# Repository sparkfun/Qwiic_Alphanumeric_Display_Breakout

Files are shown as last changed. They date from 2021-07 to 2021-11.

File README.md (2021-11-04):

SparkFun Qwiic Alphanumeric Display
========================================

Qwiic Alphanumeric Display - Pink (https://cdn.sparkfun.com/assets/parts/1/5/8/5/5/16919-SparkFun_Qwiic_Alphanumeric_Display_-_Pink-Demo.jpg)

[*Qwiic Alphanumeric Display - Pink (COM-16919)*](https://www.sparkfun.com/products/16919)

Qwiic Alphanumeric Display - Green (https://cdn.sparkfun.com/assets/parts/1/8/0/2/2/18566-SparkFun_Qwiic_Alphanumeric_Display_-_Green-Demo.jpg)

[*Qwiic Alphanumeric Display - Green (COM-18566)*](https://www.sparkfun.com/products/18566)

Qwiic Alphanumeric Display - Red (https://cdn.sparkfun.com/assets/parts/1/5/8/5/2/16916-SparkFun_Qwiic_Alphanumeric_Display_-_Red-Demo.jpg)

[*Qwiic Alphanumeric Display - Red (COM-16916)*](https://www.sparkfun.com/products/16916)

Qwiic Alphanumeric Display - Blue (https://cdn.sparkfun.com/assets/parts/1/5/8/5/3/16917-SparkFun_Qwiic_Alphanumeric_Display_-_Blue-Demo.jpg)

[*Qwiic Alphanumeric Display - Blue (COM-16917)*](https://www.sparkfun.com/products/16917)

Qwiic Alphanumeric Display - Purple (https://cdn.sparkfun.com/assets/parts/1/5/8/5/4/16918-SparkFun_Qwiic_Alphanumeric_Display_-_Purple-Demo.jpg)

[*Qwiic Alphanumeric Display - Purple (COM-16918)*](https://www.sparkfun.com/products/16918)

Qwiic Alphanumeric Display - White (https://cdn.sparkfun.com/assets/parts/1/8/0/2/0/18565-SparkFun_Qwiic_Alphanumeric_Display_-_White-Demo.jpg)

[*Qwiic Alphanumeric Display - White (COM-18565)*](https://www.sparkfun.com/products/18565)

We are quite familiar with seven-segment displays. We see them on our alarm clocks, ovens, and microwaves. By adding more segments to each digit you can display more than just numbers! Introducing the brand new SparkFun Qwiic Alphanumeric Display. These fourteen-segment digits allow you to display all sorts of numbers, characters, and symbols. With [Qwiic](https://www.sparkfun.com/qwiic), simply plug it in and go. No soldering, no figuring out which is SDA or SCL, and no voltage regulation or translation required! 

The [SparkFun Alphanumeric Display Arduino library](https://github.com/sparkfun/SparkFun_Alphanumeric_Display_Arduino_Library) makes printing strings to the display as easy as calling the print() function. With this library, you'll be able to send I<sup>2</sup>C commands to the VK16K33 LED driver chip to light up segments (including the decimal point or colon) and even scroll your string across the display. You can download the library through the Arduino library manager by searching 'SparkFun Alphanumeric Display' or you can get the GitHub repo as a .zip file and install the library from there.

The VK16K33 also supports I<sup>2</sup>C address configuration. Simply close a combination of the address jumpers on the back and you can communicate with up to four displays on the same bus. Our slim board design also features detachable standoff holes, vertical Qwiic connectors, and internal mounting holes.

SparkFun labored with love to design this board. Feel like supporting open source hardware? 
Buy a [board]() from SparkFun!

Repository Contents
-------------------

* **/Documents** - Data sheet for the LED Driver and Alphanumeric Displays (Blue and Red)
* **/Hardware** - Eagle design files (.brd, .sch)
* **/Production** - Production panel files (.brd) within the Production folder

Documentation
--------------
* **[Library](https://github.com/sparkfun/SparkFun_Alphanumeric_Display_Arduino_Library)** - <LANGUAGE> library for the Qwiic Alphanumeric Display Breakout.
* **[Hookup Guide](https://learn.sparkfun.com/tutorials/sparkfun-qwiic-alphanumeric-display-hookup-guide)** - Basic hookup guide for the Qwiic Alphanumeric Display Breakout.

License Information
-------------------

This product is _**open source**_! 

Please review the LICENSE.md file for license information. 

If you have any questions or concerns on licensing, please contact technical support on our [SparkFun forums](https://forum.sparkfun.com/viewforum.php?f=152).

Distributed as-is; no warranty is given.

- Your friends at SparkFun.

_<COLLABORATION CREDIT>_

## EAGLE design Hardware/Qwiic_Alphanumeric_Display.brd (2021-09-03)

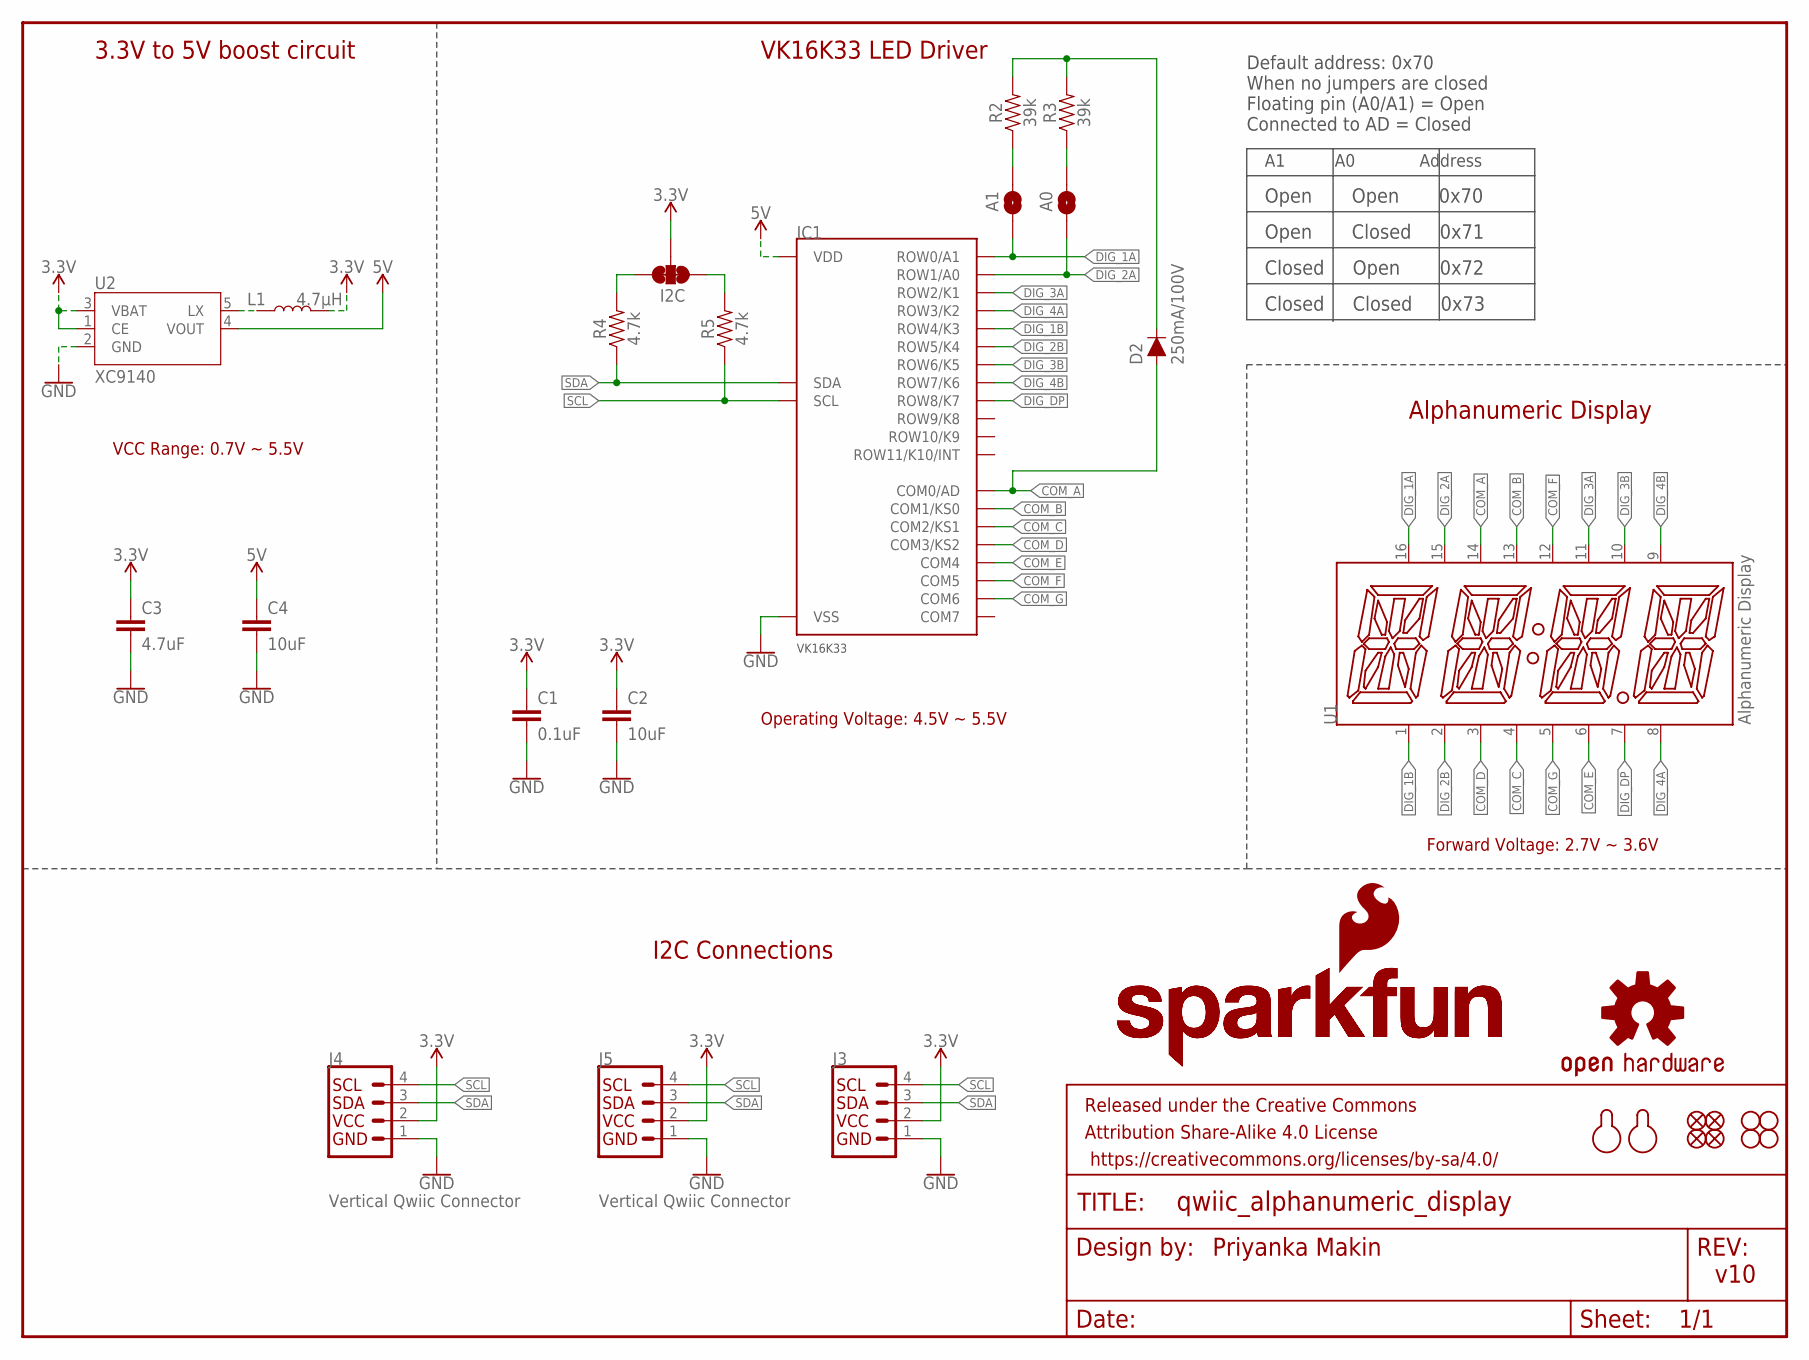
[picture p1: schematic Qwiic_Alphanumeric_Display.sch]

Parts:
A0, A1: JUMPER-SMT_2_NO_SILK; SMT-JUMPER_2_NO_SILK
C1: 0.1uF; 0603
C2, C4: 10uF; 0603
C3: 4.7uF; 0603
D2: 250mA/100V; SOD-323
FD1, FD2, FD3, FD4: FIDUCIAL1X2; FIDUCIAL-1X2
FRAME1: FRAME-LETTER; CREATIVE_COMMONS
H1, H2, H3, H4: STAND-OFF
I2C: JUMPER-SMT_3_2-NC_TRACE_NO-SILK; SMT-JUMPER_3_2-NC_TRACE_NO-SILK
IC1: VK16K33VK16K33; VK16K33
J3: I2C_STANDARD_NO_SILK; 1X04_NO_SILK
J4, J5: Vertical Qwiic Connector; JST04_1MM_VERT
L1: 4.7µH; INDUCTOR_4.7UH
LOGO1: OSHW-LOGOMINI; OSHW-LOGO-MINI
LOGO2, LOGO3: SFE_LOGO_NAME.1_INCH; SFE_LOGO_NAME_.1
LOGO4: SFE_LOGO_FLAME.1_INCH; SFE_LOGO_FLAME_.1
R2, R3: 39k; 0603
R4, R5: 4.7k; 0402-TIGHT
U1: Alphanumeric Display; SILSMART_DISPLAY
U2: XC9140; SOT23-5
U$3, U$7: MOUNTING_HOLE_M2-0.4X6

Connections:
3.3V: C1.1, C2.1, C3.1, I2C.2, J3.2, J4.2, J5.2, L1.P$2 (2), U2.1 (CE), U2.3 (VBAT)
5V: C4.1, IC1.24 (VDD), U2.4 (VOUT)
COM_A: D2.A, IC1.2 (COM0/AD), U1.14 (COM_A)
COM_B: IC1.3 (COM1/KS0), U1.13 (COM_B)
COM_C: IC1.4 (COM2/KS1), U1.4 (COM_C)
COM_D: IC1.5 (COM3/KS2), U1.3 (COM_D)
COM_E: IC1.6 (COM4), U1.6 (COM_E)
COM_F: IC1.7 (COM5), U1.12 (COM_F)
COM_G: IC1.8 (COM6), U1.5 (COM_G1)
DIG_1A: A1.1, IC1.21 (ROW0/A1), U1.16 (DIG_1A)
DIG_1B: IC1.17 (ROW4/K3), U1.1 (DIG_1B)
DIG_2A: A0.1, IC1.20 (ROW1/A0), U1.15 (DIG_2A)
DIG_2B: IC1.16 (ROW5/K4), U1.2 (DIG_2B)
DIG_3A: IC1.19 (ROW2/K1), U1.11 (DIG_3A)
DIG_3B: IC1.15 (ROW6/K5), U1.10 (DIG_3B)
DIG_4A: IC1.18 (ROW3/K2), U1.8 (DIG_4A)
DIG_4B: IC1.14 (ROW7/K6), U1.9 (DIG_4B)
DIG_DP: IC1.13 (ROW8/K7), U1.7 (DIG_DP)
GND: C1.2, C2.2, C3.2, C4.2, IC1.1 (VSS), J3.1, J4.1, J5.1, U2.2 (GND)
unnamed: I2C.3, R4.2
unnamed: A1.2, R2.1
unnamed: A0.2, R3.1
unnamed: I2C.1, R5.2
unnamed: D2.C, R2.2, R3.2
unnamed: L1.P$1 (1), U2.5 (LX)
SCL: IC1.22 (SCL), J3.4, J4.4, J5.4, R5.1
SDA: IC1.23 (SDA), J3.3, J4.3, J5.3, R4.1

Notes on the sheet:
Priyanka Makin
I2C Connections
A1 A0 Address
Default address: 0x70 When no jumpers are closed Floating pin (A0/A1) = Open Connected to AD = Closed
v10
Alphanumeric Display
VK16K33 LED Driver
3.3V to 5V boost circuit
VK16K33
VCC Range: 0.7V ~ 5.5V
Operating Voltage: 4.5V ~ 5.5V
Forward Voltage: 2.7V ~ 3.6V
Open Closed 0x71
Open Open 0x70
Closed Open 0x72
Closed Closed 0x73

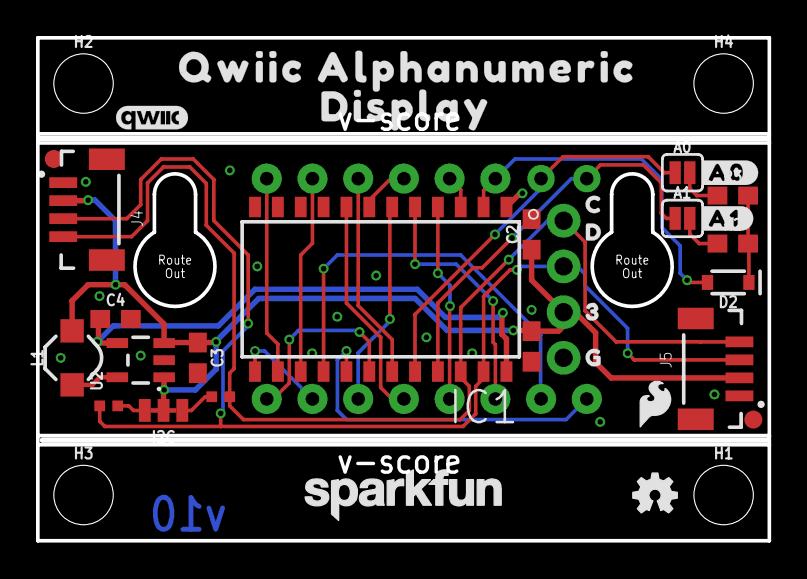
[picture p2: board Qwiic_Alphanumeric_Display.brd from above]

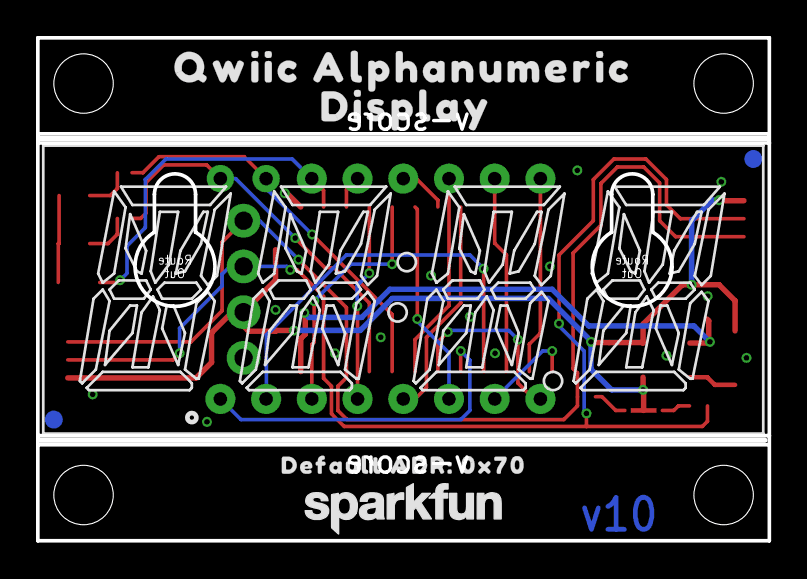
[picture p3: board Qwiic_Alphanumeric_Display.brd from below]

Board: 2 copper layers, 40.6 x 27.9 mm, 46 parts (7 on the bottom side), 27 nets.

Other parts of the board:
U$1: DEFAULT_ADR#_0X700
U$6: QWIIC_4MM
U$8, U$9: QWIIC_ALPHANUMERIC0
U$10, U$11: DISPLAY0
U$12: #A0#0
U$13: #A1#0
U$14: C0
U$15: D0
U$16: 30
U$17: G0

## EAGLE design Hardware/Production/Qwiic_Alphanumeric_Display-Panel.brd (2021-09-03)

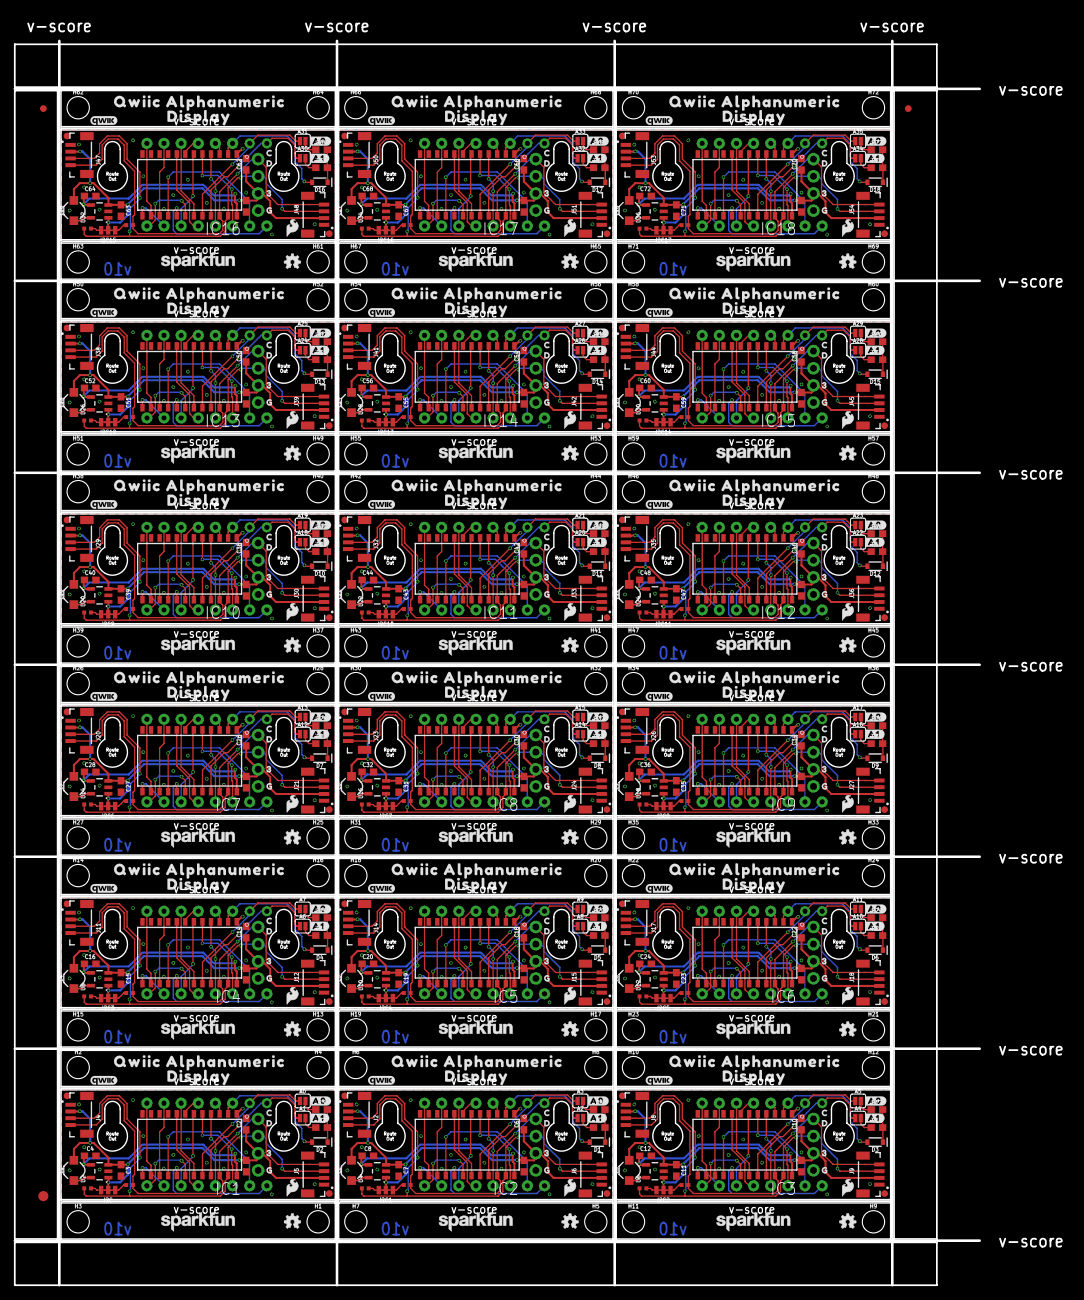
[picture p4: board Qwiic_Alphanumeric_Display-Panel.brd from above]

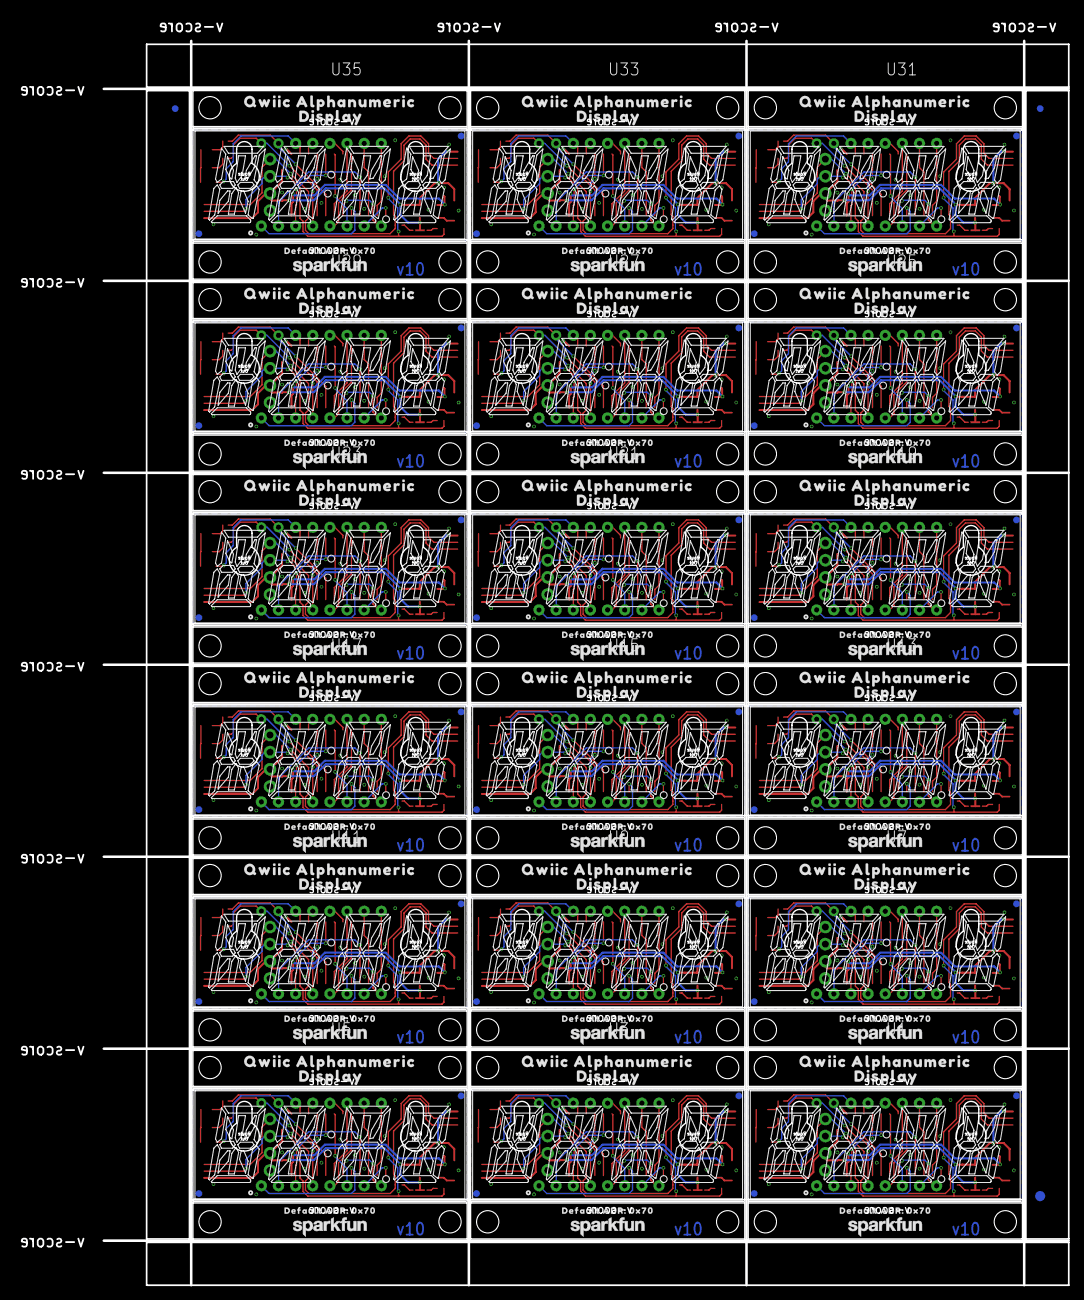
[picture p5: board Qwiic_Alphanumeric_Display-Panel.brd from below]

Board: 2 copper layers, 143.0 x 184.4 mm, 816 parts (129 on the bottom side), 486 nets.

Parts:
A0, A1, A2, A3, A4, A5, A6, A7, A8, A9, A10, A11, A12, A13, A14, A15, A16, A17, A18, A19, A20, A21, A22, A23, A24, A25, A26, A27, A28, A29, A30, A31, A32, A33, A34, A35: JUMPER-SMT_2_NO_SILK; SMT-JUMPER_2_NO_SILK
C1, C5, C9, C13, C17, C21, C25, C29, C33, C37, C41, C45, C49, C53, C57, C61, C65, C69: 0.1uF; 0603
C2, C4, C6, C8, C10, C12, C14, C16, C18, C20, C22, C24, C26, C28, C30, C32, C34, C36, C38, C40, C42, C44, C46, C48, C50, C52, C54, C56, C58, C60, C62, C64, C66, C68, C70, C72: 10uF; 0603
C3, C7, C11, C15, C19, C23, C27, C31, C35, C39, C43, C47, C51, C55, C59, C63, C67, C71: 4.7uF; 0603
D1, D2, D3, D4, D5, D6, D7, D8, D9, D10, D11, D12, D13, D14, D15, D16, D17, D18: 250mA/100V; SOD-323
E$1, E$2, E$3, E$4: FIDUCIAL-1X2
E$5, E$6: FIDUCIAL-1.5X3
FD1, FD2, FD3, FD4, FD5, FD6, FD7, FD8, FD9, FD10, FD11, FD12, FD13, FD14, FD15, FD16, FD17, FD18, FD19, FD20, FD21, FD22, FD23, FD24, FD25, FD26, FD27, FD28, FD29, FD30, FD31, FD32, FD33, FD34, FD35, FD36, FD37, FD38, FD39, FD40, FD41, FD42, FD43, FD44, FD45, FD46, FD47, FD48, FD49, FD50, FD51, FD52, FD53, FD54, FD55, FD56, FD57, FD58, FD59, FD60, FD61, FD62, FD63, FD64, FD65, FD66, FD67, FD68, FD69, FD70, FD71, FD72: FIDUCIAL1X2; FIDUCIAL-1X2
H1, H2, H3, H4, H5, H6, H7, H8, H9, H10, H11, H12, H13, H14, H15, H16, H17, H18, H19, H20, H21, H22, H23, H24, H25, H26, H27, H28, H29, H30, H31, H32, H33, H34, H35, H36, H37, H38, H39, H40, H41, H42, H43, H44, H45, H46, H47, H48, H49, H50, H51, H52, H53, H54, H55, H56, H57, H58, H59, H60, H61, H62, H63, H64, H65, H66, H67, H68, H69, H70, H71, H72: STAND-OFF
I2C, I2C1, I2C2, I2C3, I2C4, I2C5, I2C6, I2C7, I2C8, I2C9, I2C10, I2C11, I2C12, I2C13, I2C14, I2C15, I2C16, I2C17: JUMPER-SMT_3_2-NC_TRACE_NO-SILK; SMT-JUMPER_3_2-NC_TRACE_NO-SILK
IC1, IC2, IC3, IC4, IC5, IC6, IC7, IC8, IC9, IC10, IC11, IC12, IC13, IC14, IC15, IC16, IC17, IC18: VK16K33
J1, J3, J7, J10, J13, J16, J19, J22, J25, J28, J31, J34, J37, J40, J43, J46, J49, J52: 1X04_NO_SILK
J2, J4, J5, J6, J8, J9, J11, J12, J14, J15, J17, J18, J20, J21, J23, J24, J26, J27, J29, J30, J32, J33, J35, J36, J38, J39, J41, J42, J44, J45, J47, J48, J50, J51, J53, J54: Vertical Qwiic Connector; JST04_1MM_VERT
L1, L2, L3, L4, L5, L6, L7, L8, L9, L10, L11, L12, L13, L14, L15, L16, L17, L18: 4.7µH; INDUCTOR_4.7UH
LOGO1, LOGO5, LOGO9, LOGO13, LOGO17, LOGO21, LOGO25, LOGO29, LOGO33, LOGO37, LOGO41, LOGO45, LOGO49, LOGO53, LOGO57, LOGO61, LOGO65, LOGO69: OSHW-LOGOMINI; OSHW-LOGO-MINI
LOGO2, LOGO3, LOGO6, LOGO7, LOGO10, LOGO11, LOGO14, LOGO15, LOGO18, LOGO19, LOGO22, LOGO23, LOGO26, LOGO27, LOGO30, LOGO31, LOGO34, LOGO35, LOGO38, LOGO39, LOGO42, LOGO43, LOGO46, LOGO47, LOGO50, LOGO51, LOGO54, LOGO55, LOGO58, LOGO59, LOGO62, LOGO63, LOGO66, LOGO67, LOGO70, LOGO71: SFE_LOGO_NAME.1_INCH; SFE_LOGO_NAME_.1
LOGO4, LOGO8, LOGO12, LOGO16, LOGO20, LOGO24, LOGO28, LOGO32, LOGO36, LOGO40, LOGO44, LOGO48, LOGO52, LOGO56, LOGO60, LOGO64, LOGO68, LOGO72: SFE_LOGO_FLAME.1_INCH; SFE_LOGO_FLAME_.1
R1, R4, R5, R6, R9, R10, R13, R14, R17, R18, R21, R22, R25, R26, R29, R30, R33, R34, R37, R38, R41, R42, R45, R46, R49, R50, R53, R54, R57, R58, R61, R62, R65, R66, R69, R70: 4.7k; 0402-TIGHT
R2, R3, R7, R8, R11, R12, R15, R16, R19, R20, R23, R24, R27, R28, R31, R32, R35, R36, R39, R40, R43, R44, R47, R48, R51, R52, R55, R56, R59, R60, R63, R64, R67, R68, R71, R72: 39k; 0603
U1, U3, U5, U7, U9, U11, U13, U15, U17, U19, U21, U23, U25, U27, U29, U31, U33, U35: Alphanumeric Display; SILSMART_DISPLAY
U2, U4, U6, U8, U10, U12, U14, U16, U18, U20, U22, U24, U26, U28, U30, U32, U34, U36: XC9140; SOT23-5
U$1, U$28, U$42, U$56, U$70, U$84, U$98, U$112, U$126, U$140, U$154, U$168, U$182, U$196, U$210, U$224, U$238, U$252: DEFAULT_ADR#_0X700
U$2, U$6, U$29, U$43, U$57, U$71, U$85, U$99, U$113, U$127, U$141, U$155, U$169, U$183, U$197, U$211, U$225, U$239: QWIIC_4MM
U$3, U$4, U$5, U$7, U$30, U$31, U$44, U$45, U$58, U$59, U$72, U$73, U$86, U$87, U$100, U$101, U$114, U$115, U$128, U$129, U$142, U$143, U$156, U$157, U$170, U$171, U$184, U$185, U$198, U$199, U$212, U$213, U$226, U$227, U$240, U$241: MOUNTING_HOLE_M2-0.4X6
U$8, U$9, U$18, U$19, U$32, U$33, U$46, U$47, U$60, U$61, U$74, U$75, U$88, U$89, U$102, U$103, U$116, U$117, U$130, U$131, U$144, U$145, U$158, U$159, U$172, U$173, U$186, U$187, U$200, U$201, U$214, U$215, U$228, U$229, U$242, U$243: QWIIC_ALPHANUMERIC0
U$10, U$11, U$20, U$21, U$34, U$35, U$48, U$49, U$62, U$63, U$76, U$77, U$90, U$91, U$104, U$105, U$118, U$119, U$132, U$133, U$146, U$147, U$160, U$161, U$174, U$175, U$188, U$189, U$202, U$203, U$216, U$217, U$230, U$231, U$244, U$245: DISPLAY0
U$12, U$22, U$36, U$50, U$64, U$78, U$92, U$106, U$120, U$134, U$148, U$162, U$176, U$190, U$204, U$218, U$232, U$246: #A0#0
U$13, U$23, U$37, U$51, U$65, U$79, U$93, U$107, U$121, U$135, U$149, U$163, U$177, U$191, U$205, U$219, U$233, U$247: #A1#0
U$14, U$24, U$38, U$52, U$66, U$80, U$94, U$108, U$122, U$136, U$150, U$164, U$178, U$192, U$206, U$220, U$234, U$248: C0
U$15, U$25, U$39, U$53, U$67, U$81, U$95, U$109, U$123, U$137, U$151, U$165, U$179, U$193, U$207, U$221, U$235, U$249: D0
U$16, U$26, U$40, U$54, U$68, U$82, U$96, U$110, U$124, U$138, U$152, U$166, U$180, U$194, U$208, U$222, U$236, U$250: 30
U$17, U$27, U$41, U$55, U$69, U$83, U$97, U$111, U$125, U$139, U$153, U$167, U$181, U$195, U$209, U$223, U$237, U$251: G0

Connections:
3.3V: C1.1, C2.1, C3.1, I2C.2, J3.2, J4.2, J5.2, L1.P$2, U2.1, U2.3
3.3V1: C5.1, C6.1, C7.1, I2C1.2, J1.2, J2.2, J6.2, L2.P$2, U4.1, U4.3
3.3V2: C9.1, C10.1, C11.1, I2C2.2, J7.2, J8.2, J9.2, L3.P$2, U6.1, U6.3
3.3V3: C13.1, C14.1, C15.1, I2C3.2, J10.2, J11.2, J12.2, L4.P$2, U8.1, U8.3
3.3V4: C17.1, C18.1, C19.1, I2C4.2, J13.2, J14.2, J15.2, L5.P$2, U10.1, U10.3
3.3V5: C21.1, C22.1, C23.1, I2C5.2, J16.2, J17.2, J18.2, L6.P$2, U12.1, U12.3
3.3V6: C25.1, C26.1, C27.1, I2C6.2, J19.2, J20.2, J21.2, L7.P$2, U14.1, U14.3
3.3V7: C29.1, C30.1, C31.1, I2C7.2, J22.2, J23.2, J24.2, L8.P$2, U16.1, U16.3
3.3V8: C33.1, C34.1, C35.1, I2C8.2, J25.2, J26.2, J27.2, L9.P$2, U18.1, U18.3
3.3V9: C37.1, C38.1, C39.1, I2C9.2, J28.2, J29.2, J30.2, L10.P$2, U20.1, U20.3
3.3V10: C41.1, C42.1, C43.1, I2C10.2, J31.2, J32.2, J33.2, L11.P$2, U22.1, U22.3
3.3V11: C45.1, C46.1, C47.1, I2C11.2, J34.2, J35.2, J36.2, L12.P$2, U24.1, U24.3
3.3V12: C49.1, C50.1, C51.1, I2C12.2, J37.2, J38.2, J39.2, L13.P$2, U26.1, U26.3
3.3V13: C53.1, C54.1, C55.1, I2C13.2, J40.2, J41.2, J42.2, L14.P$2, U28.1, U28.3
3.3V14: C57.1, C58.1, C59.1, I2C14.2, J43.2, J44.2, J45.2, L15.P$2, U30.1, U30.3
3.3V15: C61.1, C62.1, C63.1, I2C15.2, J46.2, J47.2, J48.2, L16.P$2, U32.1, U32.3
3.3V16: C65.1, C66.1, C67.1, I2C16.2, J49.2, J50.2, J51.2, L17.P$2, U34.1, U34.3
3.3V17: C69.1, C70.1, C71.1, I2C17.2, J52.2, J53.2, J54.2, L18.P$2, U36.1, U36.3
5V: C4.1, IC1.24, U2.4
5V1: C8.1, IC2.24, U4.4
5V2: C12.1, IC3.24, U6.4
5V3: C16.1, IC4.24, U8.4
5V4: C20.1, IC5.24, U10.4
5V5: C24.1, IC6.24, U12.4
5V6: C28.1, IC7.24, U14.4
5V7: C32.1, IC8.24, U16.4
5V8: C36.1, IC9.24, U18.4
5V9: C40.1, IC10.24, U20.4
5V10: C44.1, IC11.24, U22.4
5V11: C48.1, IC12.24, U24.4
5V12: C52.1, IC13.24, U26.4
5V13: C56.1, IC14.24, U28.4
5V14: C60.1, IC15.24, U30.4
5V15: C64.1, IC16.24, U32.4
5V16: C68.1, IC17.24, U34.4
5V17: C72.1, IC18.24, U36.4
COM_A: D2.A, IC1.2, U1.14
COM_A1: D1.A, IC2.2, U3.14
COM_A2: D3.A, IC3.2, U5.14
COM_A3: D4.A, IC4.2, U7.14
COM_A4: D5.A, IC5.2, U9.14
COM_A5: D6.A, IC6.2, U11.14
COM_A6: D7.A, IC7.2, U13.14
COM_A7: D8.A, IC8.2, U15.14
COM_A8: D9.A, IC9.2, U17.14
COM_A9: D10.A, IC10.2, U19.14
COM_A10: D11.A, IC11.2, U21.14
COM_A11: D12.A, IC12.2, U23.14
COM_A12: D13.A, IC13.2, U25.14
COM_A13: D14.A, IC14.2, U27.14
COM_A14: D15.A, IC15.2, U29.14
COM_A15: D16.A, IC16.2, U31.14
COM_A16: D17.A, IC17.2, U33.14
COM_A17: D18.A, IC18.2, U35.14
COM_B: IC1.3, U1.13
COM_B1: IC2.3, U3.13
COM_B2: IC3.3, U5.13
COM_B3: IC4.3, U7.13
COM_B4: IC5.3, U9.13
COM_B5: IC6.3, U11.13
COM_B6: IC7.3, U13.13
COM_B7: IC8.3, U15.13
COM_B8: IC9.3, U17.13
COM_B9: IC10.3, U19.13
COM_B10: IC11.3, U21.13
COM_B11: IC12.3, U23.13
COM_B12: IC13.3, U25.13
COM_B13: IC14.3, U27.13
COM_B14: IC15.3, U29.13
COM_B15: IC16.3, U31.13
COM_B16: IC17.3, U33.13
COM_B17: IC18.3, U35.13
COM_C: IC1.4, U1.4
COM_C1: IC2.4, U3.4
COM_C2: IC3.4, U5.4
COM_C3: IC4.4, U7.4
COM_C4: IC5.4, U9.4
COM_C5: IC6.4, U11.4
COM_C6: IC7.4, U13.4
COM_C7: IC8.4, U15.4
COM_C8: IC9.4, U17.4
COM_C9: IC10.4, U19.4
COM_C10: IC11.4, U21.4
COM_C11: IC12.4, U23.4
COM_C12: IC13.4, U25.4
COM_C13: IC14.4, U27.4
COM_C14: IC15.4, U29.4
COM_C15: IC16.4, U31.4
COM_C16: IC17.4, U33.4
COM_C17: IC18.4, U35.4
COM_D: IC1.5, U1.3
COM_D1: IC2.5, U3.3
COM_D2: IC3.5, U5.3
COM_D3: IC4.5, U7.3
COM_D4: IC5.5, U9.3
COM_D5: IC6.5, U11.3
COM_D6: IC7.5, U13.3
COM_D7: IC8.5, U15.3
COM_D8: IC9.5, U17.3
COM_D9: IC10.5, U19.3
COM_D10: IC11.5, U21.3
COM_D11: IC12.5, U23.3
COM_D12: IC13.5, U25.3
COM_D13: IC14.5, U27.3
COM_D14: IC15.5, U29.3
COM_D15: IC16.5, U31.3
COM_D16: IC17.5, U33.3
COM_D17: IC18.5, U35.3
COM_E: IC1.6, U1.6
COM_E1: IC2.6, U3.6
COM_E2: IC3.6, U5.6
COM_E3: IC4.6, U7.6
COM_E4: IC5.6, U9.6
COM_E5: IC6.6, U11.6
COM_E6: IC7.6, U13.6
COM_E7: IC8.6, U15.6
COM_E8: IC9.6, U17.6
COM_E9: IC10.6, U19.6
COM_E10: IC11.6, U21.6
COM_E11: IC12.6, U23.6
COM_E12: IC13.6, U25.6
COM_E13: IC14.6, U27.6
COM_E14: IC15.6, U29.6
COM_E15: IC16.6, U31.6
COM_E16: IC17.6, U33.6
COM_E17: IC18.6, U35.6
COM_F: IC1.7, U1.12
COM_F1: IC2.7, U3.12
COM_F2: IC3.7, U5.12
COM_F3: IC4.7, U7.12
COM_F4: IC5.7, U9.12
COM_F5: IC6.7, U11.12
COM_F6: IC7.7, U13.12
COM_F7: IC8.7, U15.12
COM_F8: IC9.7, U17.12
COM_F9: IC10.7, U19.12
COM_F10: IC11.7, U21.12
COM_F11: IC12.7, U23.12
COM_F12: IC13.7, U25.12
COM_F13: IC14.7, U27.12
COM_F14: IC15.7, U29.12
COM_F15: IC16.7, U31.12
COM_F16: IC17.7, U33.12
COM_F17: IC18.7, U35.12
COM_G: IC1.8, U1.5
COM_G1: IC2.8, U3.5
COM_G2: IC3.8, U5.5
COM_G3: IC4.8, U7.5
COM_G4: IC5.8, U9.5
COM_G5: IC6.8, U11.5
COM_G6: IC7.8, U13.5
COM_G7: IC8.8, U15.5
COM_G8: IC9.8, U17.5
COM_G9: IC10.8, U19.5
COM_G10: IC11.8, U21.5
COM_G11: IC12.8, U23.5
COM_G12: IC13.8, U25.5
COM_G13: IC14.8, U27.5
COM_G14: IC15.8, U29.5
COM_G15: IC16.8, U31.5
COM_G16: IC17.8, U33.5
COM_G17: IC18.8, U35.5
DIG_1A: A1.1, IC1.21, U1.16
DIG_1A1: A2.1, IC2.21, U3.16
DIG_1A2: A4.1, IC3.21, U5.16
DIG_1A3: A6.1, IC4.21, U7.16
DIG_1A4: A8.1, IC5.21, U9.16
DIG_1A5: A10.1, IC6.21, U11.16
DIG_1A6: A12.1, IC7.21, U13.16
DIG_1A7: A14.1, IC8.21, U15.16
DIG_1A8: A16.1, IC9.21, U17.16
DIG_1A9: A18.1, IC10.21, U19.16
DIG_1A10: A20.1, IC11.21, U21.16
DIG_1A11: A22.1, IC12.21, U23.16
DIG_1A12: A24.1, IC13.21, U25.16
DIG_1A13: A26.1, IC14.21, U27.16
DIG_1A14: A28.1, IC15.21, U29.16
DIG_1A15: A30.1, IC16.21, U31.16
DIG_1A16: A32.1, IC17.21, U33.16
DIG_1A17: A34.1, IC18.21, U35.16
DIG_1B: IC1.17, U1.1
DIG_1B1: IC2.17, U3.1
DIG_1B2: IC3.17, U5.1
DIG_1B3: IC4.17, U7.1
DIG_1B4: IC5.17, U9.1
DIG_1B5: IC6.17, U11.1
DIG_1B6: IC7.17, U13.1
DIG_1B7: IC8.17, U15.1
DIG_1B8: IC9.17, U17.1
DIG_1B9: IC10.17, U19.1
DIG_1B10: IC11.17, U21.1
DIG_1B11: IC12.17, U23.1
DIG_1B12: IC13.17, U25.1
DIG_1B13: IC14.17, U27.1
DIG_1B14: IC15.17, U29.1
DIG_1B15: IC16.17, U31.1
DIG_1B16: IC17.17, U33.1
DIG_1B17: IC18.17, U35.1
DIG_2A: A0.1, IC1.20, U1.15
DIG_2A1: A3.1, IC2.20, U3.15
DIG_2A2: A5.1, IC3.20, U5.15
DIG_2A3: A7.1, IC4.20, U7.15
DIG_2A4: A9.1, IC5.20, U9.15
DIG_2A5: A11.1, IC6.20, U11.15
DIG_2A6: A13.1, IC7.20, U13.15
DIG_2A7: A15.1, IC8.20, U15.15
DIG_2A8: A17.1, IC9.20, U17.15
DIG_2A9: A19.1, IC10.20, U19.15
DIG_2A10: A21.1, IC11.20, U21.15
DIG_2A11: A23.1, IC12.20, U23.15
DIG_2A12: A25.1, IC13.20, U25.15
DIG_2A13: A27.1, IC14.20, U27.15
DIG_2A14: A29.1, IC15.20, U29.15
DIG_2A15: A31.1, IC16.20, U31.15
DIG_2A16: A33.1, IC17.20, U33.15
DIG_2A17: A35.1, IC18.20, U35.15
DIG_2B: IC1.16, U1.2
DIG_2B1: IC2.16, U3.2
DIG_2B2: IC3.16, U5.2
DIG_2B3: IC4.16, U7.2
DIG_2B4: IC5.16, U9.2
DIG_2B5: IC6.16, U11.2
DIG_2B6: IC7.16, U13.2
DIG_2B7: IC8.16, U15.2
DIG_2B8: IC9.16, U17.2
DIG_2B9: IC10.16, U19.2
DIG_2B10: IC11.16, U21.2
DIG_2B11: IC12.16, U23.2
DIG_2B12: IC13.16, U25.2
DIG_2B13: IC14.16, U27.2
DIG_2B14: IC15.16, U29.2
DIG_2B15: IC16.16, U31.2
DIG_2B16: IC17.16, U33.2
DIG_2B17: IC18.16, U35.2
DIG_3A: IC1.19, U1.11
DIG_3A1: IC2.19, U3.11
DIG_3A2: IC3.19, U5.11
DIG_3A3: IC4.19, U7.11
DIG_3A4: IC5.19, U9.11
DIG_3A5: IC6.19, U11.11
DIG_3A6: IC7.19, U13.11
DIG_3A7: IC8.19, U15.11
DIG_3A8: IC9.19, U17.11
DIG_3A9: IC10.19, U19.11
DIG_3A10: IC11.19, U21.11
DIG_3A11: IC12.19, U23.11
DIG_3A12: IC13.19, U25.11
DIG_3A13: IC14.19, U27.11
DIG_3A14: IC15.19, U29.11
DIG_3A15: IC16.19, U31.11
DIG_3A16: IC17.19, U33.11
DIG_3A17: IC18.19, U35.11
DIG_3B: IC1.15, U1.10
DIG_3B1: IC2.15, U3.10
DIG_3B2: IC3.15, U5.10
DIG_3B3: IC4.15, U7.10
DIG_3B4: IC5.15, U9.10
DIG_3B5: IC6.15, U11.10
DIG_3B6: IC7.15, U13.10
DIG_3B7: IC8.15, U15.10
DIG_3B8: IC9.15, U17.10
DIG_3B9: IC10.15, U19.10
DIG_3B10: IC11.15, U21.10
DIG_3B11: IC12.15, U23.10
DIG_3B12: IC13.15, U25.10
DIG_3B13: IC14.15, U27.10
DIG_3B14: IC15.15, U29.10
DIG_3B15: IC16.15, U31.10
DIG_3B16: IC17.15, U33.10
DIG_3B17: IC18.15, U35.10
DIG_4A: IC1.18, U1.8
DIG_4A1: IC2.18, U3.8
DIG_4A2: IC3.18, U5.8
DIG_4A3: IC4.18, U7.8
DIG_4A4: IC5.18, U9.8
DIG_4A5: IC6.18, U11.8
DIG_4A6: IC7.18, U13.8
DIG_4A7: IC8.18, U15.8
DIG_4A8: IC9.18, U17.8
DIG_4A9: IC10.18, U19.8
DIG_4A10: IC11.18, U21.8
DIG_4A11: IC12.18, U23.8
DIG_4A12: IC13.18, U25.8
DIG_4A13: IC14.18, U27.8
DIG_4A14: IC15.18, U29.8
DIG_4A15: IC16.18, U31.8
DIG_4A16: IC17.18, U33.8
DIG_4A17: IC18.18, U35.8
DIG_4B: IC1.14, U1.9
DIG_4B1: IC2.14, U3.9
DIG_4B2: IC3.14, U5.9
DIG_4B3: IC4.14, U7.9
DIG_4B4: IC5.14, U9.9
DIG_4B5: IC6.14, U11.9
DIG_4B6: IC7.14, U13.9
DIG_4B7: IC8.14, U15.9
DIG_4B8: IC9.14, U17.9
DIG_4B9: IC10.14, U19.9
DIG_4B10: IC11.14, U21.9
DIG_4B11: IC12.14, U23.9
DIG_4B12: IC13.14, U25.9
DIG_4B13: IC14.14, U27.9
DIG_4B14: IC15.14, U29.9
DIG_4B15: IC16.14, U31.9
DIG_4B16: IC17.14, U33.9
DIG_4B17: IC18.14, U35.9
DIG_DP: IC1.13, U1.7
DIG_DP1: IC2.13, U3.7
DIG_DP2: IC3.13, U5.7
DIG_DP3: IC4.13, U7.7
DIG_DP4: IC5.13, U9.7
DIG_DP5: IC6.13, U11.7
DIG_DP6: IC7.13, U13.7
DIG_DP7: IC8.13, U15.7
DIG_DP8: IC9.13, U17.7
DIG_DP9: IC10.13, U19.7
DIG_DP10: IC11.13, U21.7
DIG_DP11: IC12.13, U23.7
DIG_DP12: IC13.13, U25.7
DIG_DP13: IC14.13, U27.7
DIG_DP14: IC15.13, U29.7
DIG_DP15: IC16.13, U31.7
DIG_DP16: IC17.13, U33.7
DIG_DP17: IC18.13, U35.7
GND: C1.2, C2.2, C3.2, C4.2, IC1.1, J3.1, J4.1, J5.1, U2.2
GND1: C5.2, C6.2, C7.2, C8.2, IC2.1, J1.1, J2.1, J6.1, U4.2
GND2: C9.2, C10.2, C11.2, C12.2, IC3.1, J7.1, J8.1, J9.1, U6.2
GND3: C13.2, C14.2, C15.2, C16.2, IC4.1, J10.1, J11.1, J12.1, U8.2
GND4: C17.2, C18.2, C19.2, C20.2, IC5.1, J13.1, J14.1, J15.1, U10.2
GND5: C21.2, C22.2, C23.2, C24.2, IC6.1, J16.1, J17.1, J18.1, U12.2
GND6: C25.2, C26.2, C27.2, C28.2, IC7.1, J19.1, J20.1, J21.1, U14.2
GND7: C29.2, C30.2, C31.2, C32.2, IC8.1, J22.1, J23.1, J24.1, U16.2
GND8: C33.2, C34.2, C35.2, C36.2, IC9.1, J25.1, J26.1, J27.1, U18.2
GND9: C37.2, C38.2, C39.2, C40.2, IC10.1, J28.1, J29.1, J30.1, U20.2
GND10: C41.2, C42.2, C43.2, C44.2, IC11.1, J31.1, J32.1, J33.1, U22.2
GND11: C45.2, C46.2, C47.2, C48.2, IC12.1, J34.1, J35.1, J36.1, U24.2
GND12: C49.2, C50.2, C51.2, C52.2, IC13.1, J37.1, J38.1, J39.1, U26.2
GND13: C53.2, C54.2, C55.2, C56.2, IC14.1, J40.1, J41.1, J42.1, U28.2
GND14: C57.2, C58.2, C59.2, C60.2, IC15.1, J43.1, J44.1, J45.1, U30.2
GND15: C61.2, C62.2, C63.2, C64.2, IC16.1, J46.1, J47.1, J48.1, U32.2
GND16: C65.2, C66.2, C67.2, C68.2, IC17.1, J49.1, J50.1, J51.1, U34.2
GND17: C69.2, C70.2, C71.2, C72.2, IC18.1, J52.1, J53.1, J54.1, U36.2
unnamed: I2C.3, R4.2
unnamed: A1.2, R2.1
unnamed: A0.2, R3.1
unnamed: I2C.1, R5.2
unnamed: A2.2, R7.1
unnamed: D2.C, R2.2, R3.2
unnamed: A3.2, R8.1
unnamed: D1.C, R7.2, R8.2
unnamed: L2.P$1, U4.5
unnamed: L1.P$1, U2.5
unnamed: I2C1.3, R1.2
unnamed: I2C1.1, R6.2
unnamed: A4.2, R11.1
unnamed: A5.2, R12.1
unnamed: D3.C, R11.2, R12.2
unnamed: L3.P$1, U6.5
unnamed: I2C2.3, R9.2
unnamed: I2C2.1, R10.2
unnamed: A6.2, R15.1
unnamed: A7.2, R16.1
unnamed: D4.C, R15.2, R16.2
unnamed: L4.P$1, U8.5
unnamed: I2C3.3, R13.2
unnamed: I2C3.1, R14.2
unnamed: A8.2, R19.1
unnamed: A9.2, R20.1
unnamed: D5.C, R19.2, R20.2
unnamed: L5.P$1, U10.5
unnamed: I2C4.3, R17.2
unnamed: I2C4.1, R18.2
unnamed: A10.2, R23.1
unnamed: A11.2, R24.1
unnamed: D6.C, R23.2, R24.2
unnamed: L6.P$1, U12.5
unnamed: I2C5.3, R21.2
unnamed: I2C5.1, R22.2
unnamed: A12.2, R27.1
unnamed: A13.2, R28.1
unnamed: D7.C, R27.2, R28.2
unnamed: L7.P$1, U14.5
unnamed: I2C6.3, R25.2
unnamed: I2C6.1, R26.2
unnamed: A14.2, R31.1
unnamed: A15.2, R32.1
unnamed: D8.C, R31.2, R32.2
unnamed: L8.P$1, U16.5
unnamed: I2C7.3, R29.2
unnamed: I2C7.1, R30.2
unnamed: A16.2, R35.1
unnamed: A17.2, R36.1
unnamed: D9.C, R35.2, R36.2
unnamed: L9.P$1, U18.5
unnamed: I2C8.3, R33.2
unnamed: I2C8.1, R34.2
unnamed: A18.2, R39.1
unnamed: A19.2, R40.1
unnamed: D10.C, R39.2, R40.2
unnamed: L10.P$1, U20.5
unnamed: I2C9.3, R37.2
unnamed: I2C9.1, R38.2
unnamed: A20.2, R43.1
unnamed: A21.2, R44.1
unnamed: D11.C, R43.2, R44.2
unnamed: L11.P$1, U22.5
unnamed: I2C10.3, R41.2
unnamed: I2C10.1, R42.2
unnamed: A22.2, R47.1
unnamed: A23.2, R48.1
unnamed: D12.C, R47.2, R48.2
unnamed: L12.P$1, U24.5
unnamed: I2C11.3, R45.2
unnamed: I2C11.1, R46.2
unnamed: A24.2, R51.1
unnamed: A25.2, R52.1
unnamed: D13.C, R51.2, R52.2
unnamed: L13.P$1, U26.5
unnamed: I2C12.3, R49.2
unnamed: I2C12.1, R50.2
unnamed: A26.2, R55.1
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

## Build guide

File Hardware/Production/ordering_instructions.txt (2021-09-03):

panel size, 137x184mm
PCB thickness, 1.6mm
number of layers, 2
soldermask color, Red
silkscreen color, White
oz copper, 1oz
finish, HASL lead free
stencils, top
pcs per panel, 18
min trace width, 0.2032mm / 0.0080in
min drill size, 0.3048mm / 0.0120in

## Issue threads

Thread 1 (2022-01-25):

Mounting options

mleonhard, 2022-01-25:
Hi SparkFun,
I wish to mount the SparkFun Qwiic Alphanumeric Display on a panel, flush.  I searched and could not find the height of the display elements in any of the docs.
1. What size standoffs should I use to mount this flush on a panel?
1. How big are the mounting holes?
1. How about including this information in the docs?
1. Additionally, you could recommend a particular set of standoffs and screws for flush panel mounting.

Thanks!
-Michael

makin-stuff, 2022-01-25:
Hi @mleonhard.

Typically, all our documentation can be found on the [SparkFun product page](https://www.sparkfun.com/products/16916). If you navigate to the "Documents" tab and click "Board Dimensions" you will see an image with all kinds of dimensions for this product.

The four mounting holes on any corner are always meant for 4-40 screws and standoffs. That's the SparkFun standard. The mounting holes in the middle of the board are meant for mounting without the board wings and fit a M2-0.4 x 6 screw.

Thanks!

mleonhard, 2022-01-25:
The "Board Dimensions" image shows only the top view, not the side view.  The data sheet is for the LED driver chip on the back.  I need to know the thickness of the display on the front, so I can choose the right standoffs to flush-mount the display.

makin-stuff, 2022-01-25:
Ok, gotcha.

For the dimensions of the display itself you want to look at the display datasheet. These live in the "Documents" folder of this repo. Any of the pdfs starting with "JMF".

These are manufactured in China, so unfortunately the data sheet is partially in Chinese which can make it hard to understand. But page three shows the mechanical dimensions. The units are in mm. Is this what you were looking for?

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

mleonhard, 2022-01-25:
Thank you! :)

Here is my plan to mount the display, which may be useful to others:

The display is 8mm tall.  8mm x (1 in / 25.4mm) = 0.315in ~= 5/16 in.  So a 3/8in standoff should leave the display slightly inset on the panel.

The mounting will be: screw head, enclosure wall, standoff, display pcb, screw head.  I will use 1/4in screws.  The standoff is 3/8in and two screws are 4/8in, leaving 1/8in (3mm) for the enclosure wall and display PCB.  If this is too much space, then I will need to put a washer on the inner screw.  Sparkfun doesn't sell washers.  I'll get them at a local store.

- [Standoff - Nylon (4-40; 3/8"; 10 pack)](https://www.sparkfun.com/products/10927)
- [Screw - Phillips Head (1/4", 4-40, 10 pack)](https://www.sparkfun.com/products/10453)

Closed 2022-01-26.

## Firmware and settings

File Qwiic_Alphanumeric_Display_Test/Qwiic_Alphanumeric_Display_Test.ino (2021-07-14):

/********************************************************************
 * This example rapid tests the hardware to verify Qwiic Alphanumeric
 * builds.
 * 
 * Priyanka Makin @ SparkFun Electronics
 * Original Creation Date: March 17, 2020
 *******************************************************************/
#include <Wire.h>
#include <SparkFun_Alphanumeric_Display.h>
HT16K33 display;

const int LED = 13;

void setup()
{
  Serial.begin(115200);
  Serial.println("Qwiic Alphanumeric Display Test");
  Wire.begin();
  pinMode(LED, OUTPUT);
}

void loop()
{
  if (display.begin() == true) {
    digitalWrite(LED, HIGH);
    Serial.println("Alphanumeric detected!");
    display.print("Milk");
  } else {
    digitalWrite(LED, LOW);
    Serial.println("Nothing detected!");
  }
}

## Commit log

2021-07-14 Add LED datasheets
2021-07-21 Update design for protos
    Add 5V boost circuit for ht16k33
    [Qwiic_Alphanumeric_Display.brd, Qwiic_Alphanumeric_Display.sch]
2021-07-21 Run schematic/board autochecklist
    Update font to vector
    Make sure all parts (except for new ones) are in SF Eagle libs
    Add measures
    [Qwiic_Alphanumeric_Display.brd, Qwiic_Alphanumeric_Display.sch]
2021-07-26 Updates after proto review
    Update HT16K33 to VK16K33
    Compared datasheets, it’s a drop in replacement!
    Removed PWR LED and jumper
    5V net now connects to the LED driver IC
    New mounting hole design
    I2C pullups became 4.7k and removed jumper
    You can only connect up to 4 displays on one bus
    [Qwiic_Alphanumeric_Display.brd, Qwiic_Alphanumeric_Display.sch]
2021-07-26 Re-generate buzzard labels
    [Qwiic_Alphanumeric_Display.brd]
2021-07-26 Run checklist
    Add voltage ranges on schematic
    [Qwiic_Alphanumeric_Display.brd, Qwiic_Alphanumeric_Display.sch]
2021-07-26 Fix mounting hole connections and add some extra dimensions
    [Qwiic_Alphanumeric_Display.brd, Qwiic_Alphanumeric_Display.sch]
2021-07-26 Add prod_id to new LED mapping IC
    [Qwiic_Alphanumeric_Display.brd, Qwiic_Alphanumeric_Display.sch]
2021-07-26 Update mounting hole placement and measures
    [Qwiic_Alphanumeric_Display.brd, Qwiic_Alphanumeric_Display.sch]
2021-07-26 Generate gerbers
    [Qwiic_Alphanumeric_Display.GBL, Qwiic_Alphanumeric_Display.GBO, Qwiic_Alphanumeric_Display.GBP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]
2021-08-18 Added test point to 5V rail
    [Qwiic_Alphanumeric_Display.brd, Qwiic_Alphanumeric_Display.sch]
2021-08-18 Remove the 5V test point after all!
    [Qwiic_Alphanumeric_Display.brd, Qwiic_Alphanumeric_Display.sch]
2021-08-31 Pete's design updates
    * Update address table with "open" and "closed"
    * Move address resistors and jumpers
    [Qwiic_Alphanumeric_Display.brd, Qwiic_Alphanumeric_Display.sch]
2021-08-31 Pete's updates
    * Some silk updates: default address and address jumper labels
    * Bump version number v01 --> v10
    [Qwiic_Alphanumeric_Display.brd, Qwiic_Alphanumeric_Display.sch]
2021-08-31 Updates from Review:
    * Mirrored J3 on sch
    * Updated via size so that they're all the same
    * Added GND vias near qwiic connectors
    * Flipped C1, re-routed
    * Moved SDA trace so that copper would flow in dead space (bottom)
    * Added I2C jumper and changed pull up resistors to 0402, 1K
    [Qwiic_Alphanumeric_Display.brd, Qwiic_Alphanumeric_Display.sch]
2021-09-02 QC Double-check updates
    * Updated footprint of silsmart display so that pin 1 indicator was in the right place
    * Moved fiducials
    [Qwiic_Alphanumeric_Display.brd, Qwiic_Alphanumeric_Display.sch]
2021-09-02 Change pullups from 1k to 4.7k
    [Qwiic_Alphanumeric_Display.brd, Qwiic_Alphanumeric_Display.sch]
2021-10-14 Removing extraneous files
    Removing extraneous files
    [Qwiic_Alphanumeric_Display.GBL, Qwiic_Alphanumeric_Display.GBO, Qwiic_Alphanumeric_Display.GBP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]

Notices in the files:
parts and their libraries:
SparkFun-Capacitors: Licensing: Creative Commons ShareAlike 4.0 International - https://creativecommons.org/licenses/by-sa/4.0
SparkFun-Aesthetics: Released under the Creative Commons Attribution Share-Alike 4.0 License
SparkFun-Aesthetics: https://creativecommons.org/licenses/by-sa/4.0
